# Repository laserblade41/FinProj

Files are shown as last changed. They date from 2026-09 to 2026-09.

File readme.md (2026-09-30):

<p align="center">
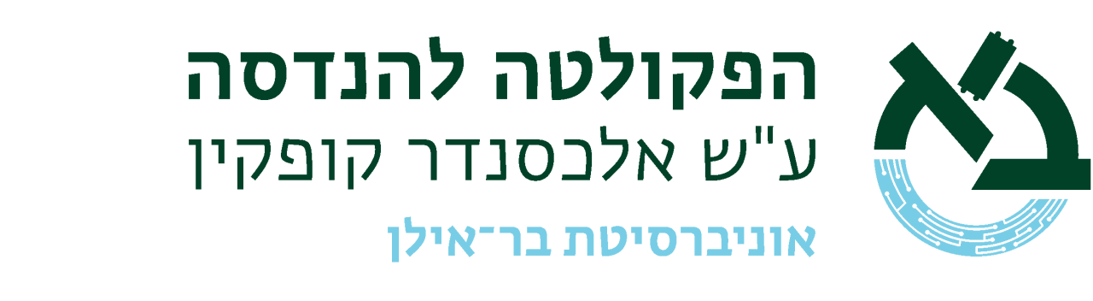
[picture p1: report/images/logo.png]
FinWatch logo
  
</p>

<h1 align="center">FinWatch</h1>

<p align="center">
  An open-source, Zephyr-powered BLE smartwatch with a modular I²C expansion port.<br>
  Final project in Computer Engineering, Bar-Ilan University (Project 323).
</p>

<p align="center">
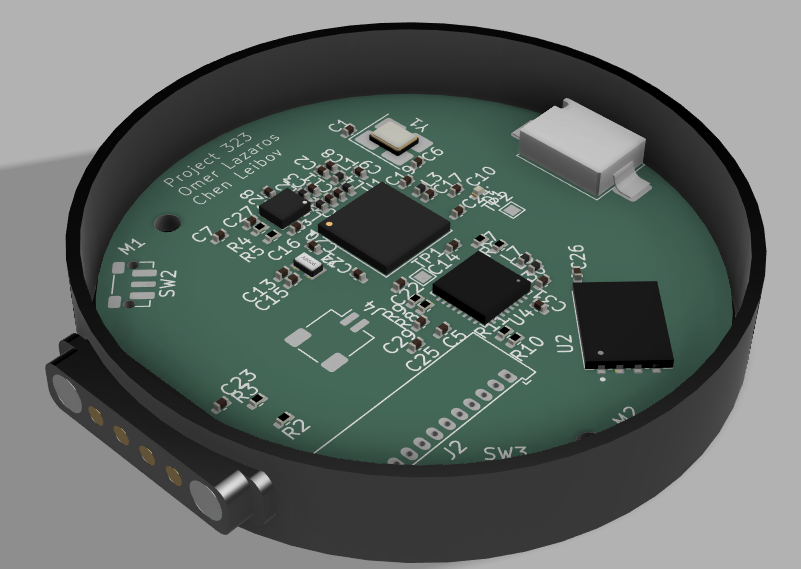
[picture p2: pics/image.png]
3D render of the FinWatch PCB in its case
  
</p>

## About

FinWatch is a complete custom smartwatch: the PCB (KiCad), the firmware (Zephyr RTOS / nRF Connect SDK) and a documented protocol for attaching new hardware to it.

Most smartwatches, commercial and open-source, are sealed. The sensors are fixed at manufacture, so a new measurement means a new watch. FinWatch asks whether a finished watch can be extended instead. A four-pin pogo connector on the back of the case carries 3.3 V, GND and an I²C bus. A module clipped onto it describes itself to the watch at runtime, and the firmware does not need to know about that module in advance.

The protocol that makes this work is the **FinWatch Module Protocol (FWMP)**. It is a self-describing, CRC-protected descriptor format. The host treats every byte from a module as untrusted and validates it before use.

The full write-up (design, protocol specification, verification, lessons learned) is in [report/main.pdf](report/main.pdf).

## Features

### Hardware

- **Nordic nRF5340** dual-core SoC (Cortex-M33 application core plus a separate network core running the BLE controller)
- **Nordic nPM1300** PMIC: Li-Po charging, fuel gauge, regulated 1.8 V and 3.3 V rails
- **GC9A01** 240×240 round LCD (SPI) with **CST816S** capacitive touch (I²C)
- **Bosch BMI270** 6-axis IMU with an any-motion interrupt, so the MCU sleeps until the wrist moves
- **Macronix MX25U51245G** 512 Mbit SPI NOR flash for assets and settings
- 32.768 kHz crystal for the RTC
- Two user buttons
- **4-pin pogo expansion port** (3.3 V, GND, SDA, SCL), level-shifted from the SoC's 1.8 V domain by a PCA9306
- 4-layer, 46 mm round PCB designed in KiCad (see [kicad/](kicad/))

### Software

- Zephyr RTOS on the nRF Connect SDK (NCS v3.2.1), with the application running in TF-M non-secure
- LVGL user interface: watch face showing time, date, battery and steps, plus a screen for the attached module
- Interrupt-driven step counting. The IMU wakes the host and the host only samples while the wrist is moving
- BLE with battery level notifications
- LittleFS on the external flash for persistent settings
- **FWMP host**: hot-plug detection, descriptor validation, input and output reports, adaptive polling, and I²C bus recovery
- Expansion runs at the lowest thread priority, so a misbehaving module cannot stall the display, sensors or radio link
- Hardware is described in the Devicetree only, so the same firmware runs on the nRF5340-DK and the custom PCB

## Expansion port and FWMP

FWMP is specified in three layers:

| Layer | What it defines |
| --- | --- |
| Electrical | Four contacts, 3.3 V supply, no pull-ups on the module side, level shifting on the watch |
| Logical | Register map and a TLV descriptor (identity, capabilities, report sizes, preferred poll rate) protected by a CRC-16 |
| Behavioural | Presence detection, enumeration, polling state machine, and recovery from faults |

The host rejects bad magic, bad protocol version, bad CRC, oversized lengths and TLV overruns. It also recovers a jammed bus. All of these paths were exercised with injected faults against a mock module. See section 4 of the report for the full specification and for how to write a compliant module.

## Hardware

<p align="center">
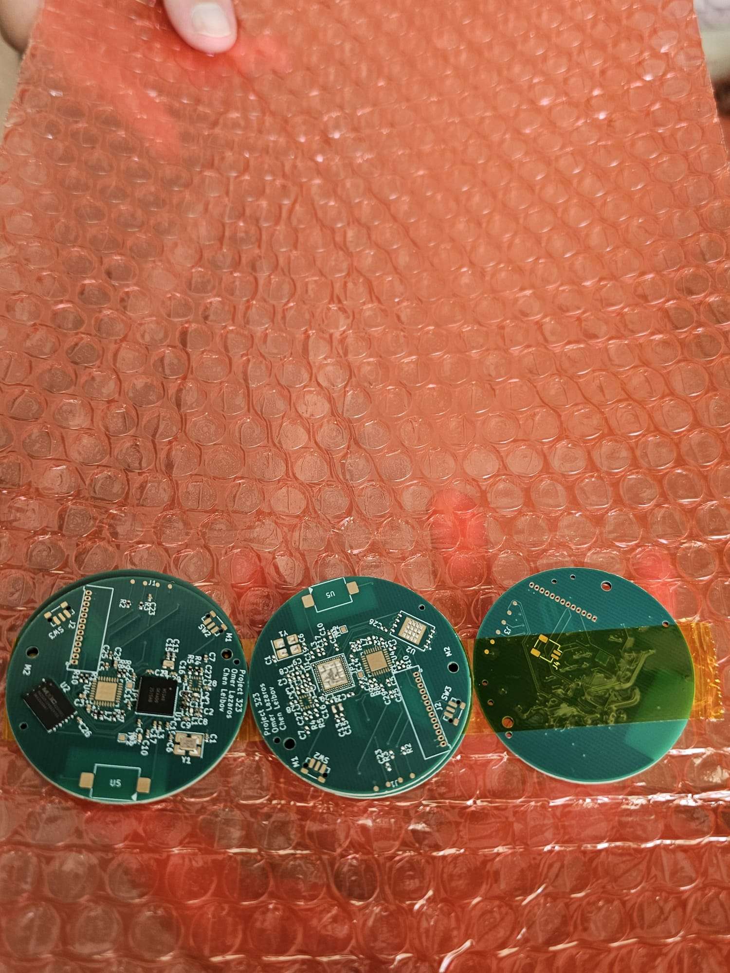
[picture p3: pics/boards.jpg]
Fabricated FinWatch PCBs
  
</p>

| Path | Contents |
| --- | --- |
| [kicad/](kicad/) | Schematic, PCB layout, custom symbols, footprints and 3D models |
| [kicad/watch_thing_alt.pdf](kicad/watch_thing_alt.pdf) | Schematic PDF |
| [kicad/components/board1_nrf5340/](kicad/components/board1_nrf5340/) | Gerber and drill files |

**Revision status**

- **Revision A** was manufactured and assembled. The power rails came up correctly, but `SWDIO` and `SWDCLK` were never routed, so the board could not be programmed.
- **Revision B** exposes SWD on test pads: `SWDIO` on TP4, `SWDCLK` on TP3, `nRESET` on TP2. The lesson from this defect became a pre-fabrication checklist, documented in the report.

## Firmware

<p align="center">
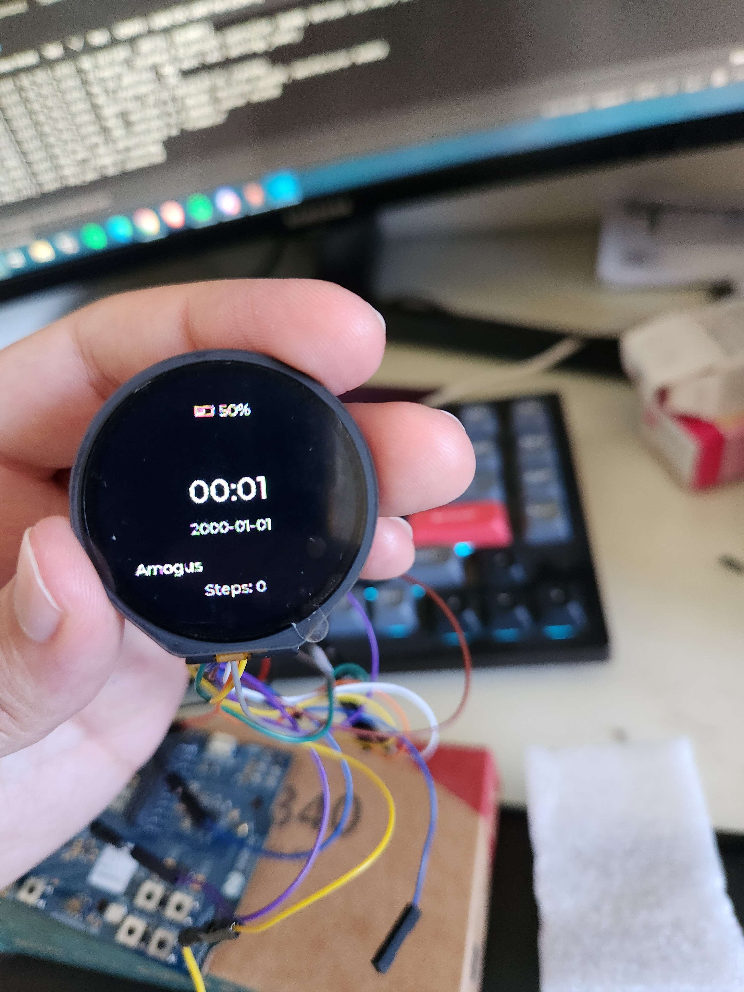
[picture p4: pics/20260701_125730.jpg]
FinWatch firmware running on the round display, wired to an nRF5340-DK
  
</p>

Above: the firmware running on the nRF5340-DK with the round display wired up.

```
code/
├── prj.conf                  Kconfig
├── boards/                   Devicetree overlays
├── child_image/hci_ipc.conf  Network-core BLE controller config
└── src/
    ├── main.c
    ├── ble/        BLE and battery notifications
    ├── buttons/    short and long press handling
    ├── display/    LVGL, watch face, module screen
    ├── expansion/  FWMP host, transport and mock module
    ├── pmic/       nPM1300: charger and fuel gauge
    ├── rtc/        timekeeping on the 32.768 kHz crystal
    ├── sensor/     BMI270 any-motion and step counting
    ├── storage/    external flash and LittleFS
    └── touch/      CST816S
```

### Building
```
IMPORTANT: the board itself does not include a bootloader to flash the firmware, in our case we used the one in the nRF5340DK.
```
1. Install the [nRF Connect SDK](https://docs.nordicsemi.com/bundle/ncs-latest/page/nrf/installation.html) **v3.2.1** and open an NCS shell.
2. Build and flash:

```sh
cd code
west build -b nrf5340dk/nrf5340/cpuapp/ns
west flash
```

To test the expansion protocol without any module hardware, enable the mock backend, which simulates a "Test Dial" module:

```sh
west build -b nrf5340dk/nrf5340/cpuapp/ns -- -DCONFIG_FINWATCH_EXPANSION_MOCK=y
```

> For the custom PCB, rename [code/boards/your_board.overlay](code/boards/your_board.overlay) to match your board target and confirm every pin marked `/* [PCB] */` against the schematic before flashing.

## Verification

- Firmware verified on the nRF5340-DK: display, touch, IMU, buttons and BLE
- FWMP verified against a mock module, including hot-plug and six injected-fault classes
- Revision A power rails verified; Revision B bring-up: *TODO*

Full results and their limits are in the report.

## Repository layout

| Folder | Contents |
| --- | --- |
| [code/](code/) | Zephyr firmware |
| [kicad/](kicad/) | PCB design files |
| [report/](report/) | Final project report (LaTeX and PDF) and presentation |
| [pics/](pics/) | Photos and renders |

## Authors

- **Omer Lazaros**
- **Chen Leibov**

Supervised by Prof. Leonid Yavitz. Project mentor: David Freud. Faculty of Engineering, Bar-Ilan University.

## Thanks

Thanks to the Zephyr Project, Nordic Semiconductor (nRF Connect SDK and its courses) and KiCad, whose open tools and documentation made this possible. [ZSWatch](https://github.com/ZSWatch/ZSWatch) was a major inspiration for this project.

## License

*TODO: pick a license (for example GPL-3.0 or MIT for the firmware and CERN-OHL for the hardware) and add a LICENSE file.*

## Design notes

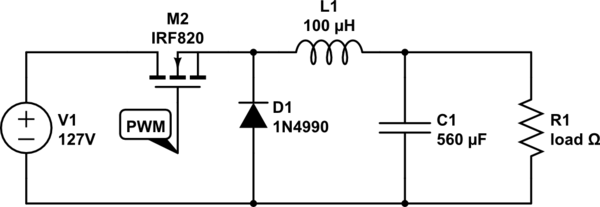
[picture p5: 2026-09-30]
report/images/buck.png

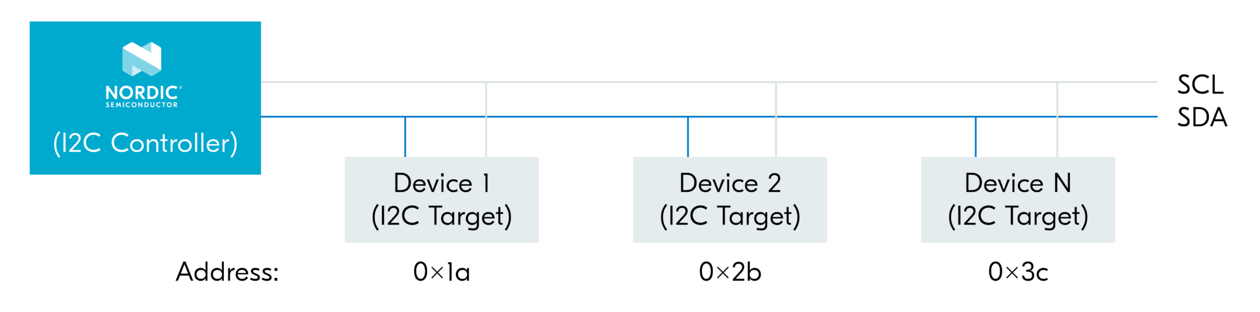
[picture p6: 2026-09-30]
report/images/i2c.png

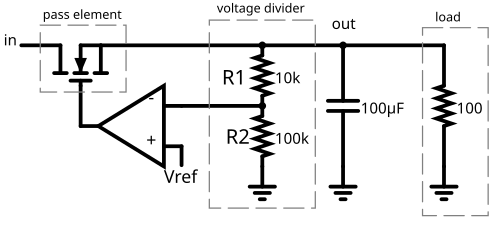
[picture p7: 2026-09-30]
report/images/ldo.png

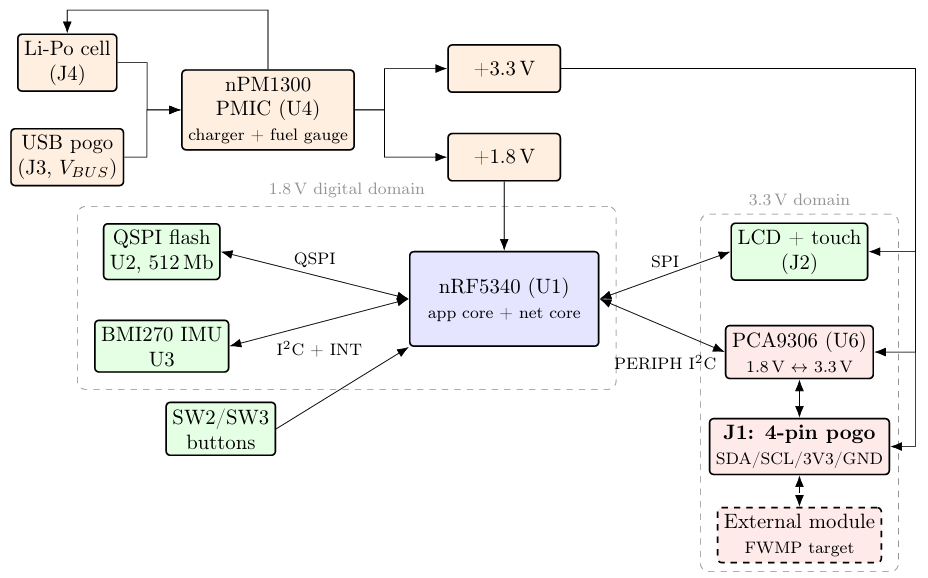
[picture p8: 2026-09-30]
report/presentation/pasted2.png

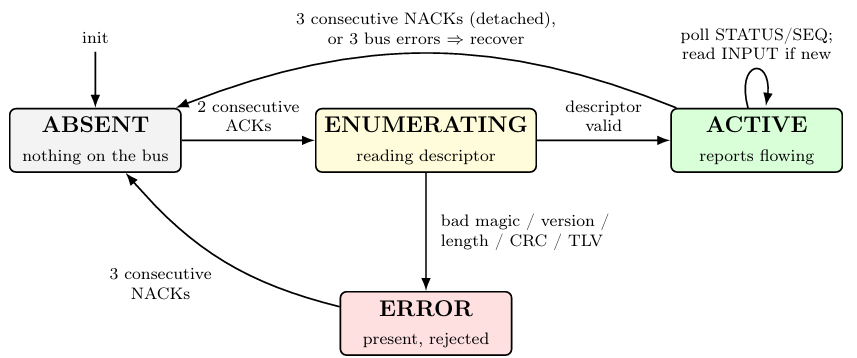
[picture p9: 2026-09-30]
report/presentation/pasted1.png

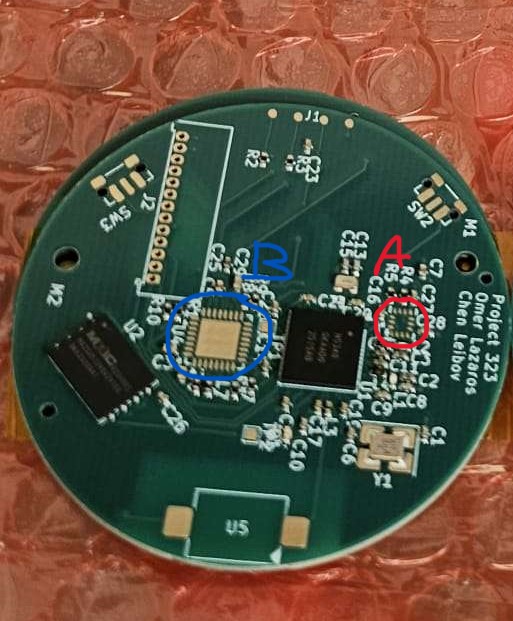
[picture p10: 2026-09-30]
pics/board_with_marks.jpg

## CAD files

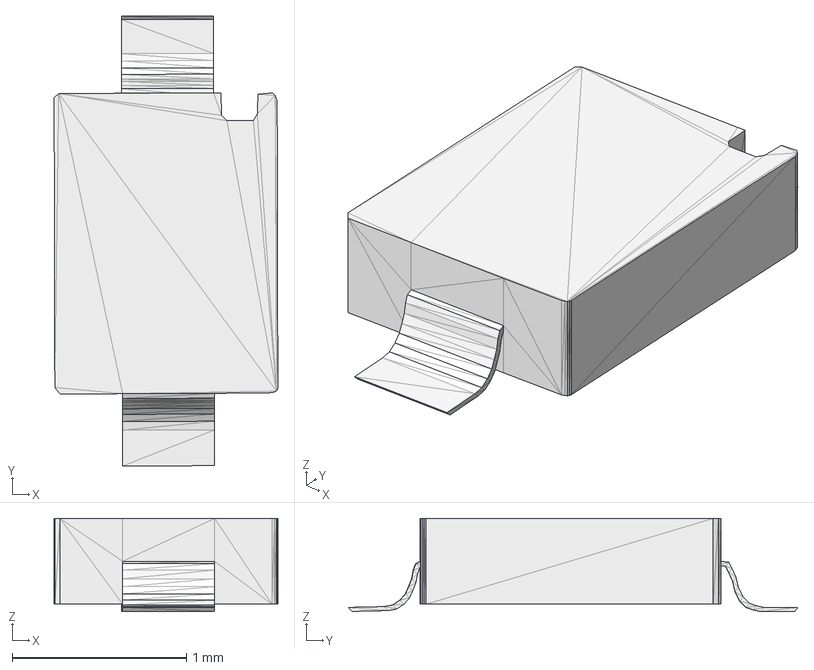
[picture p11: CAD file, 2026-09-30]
kicad/3d_models/antenna2.step
1.28 x 2.58 x 0.534 mm

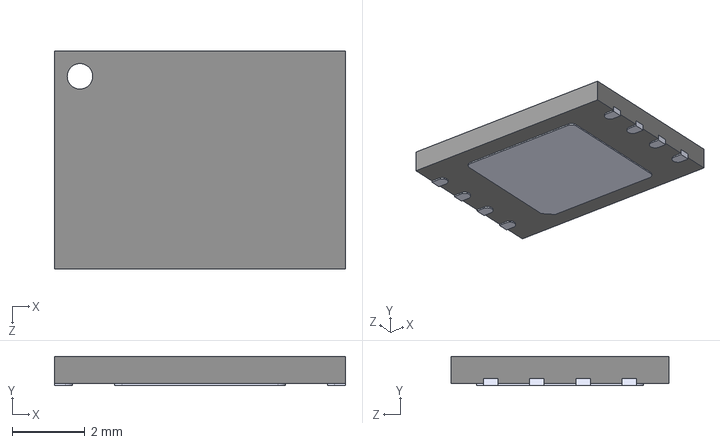
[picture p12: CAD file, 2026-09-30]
kicad/components/MX25L51245GZ2I-10G.step
8.00 x 0.8 x 6.00 mm

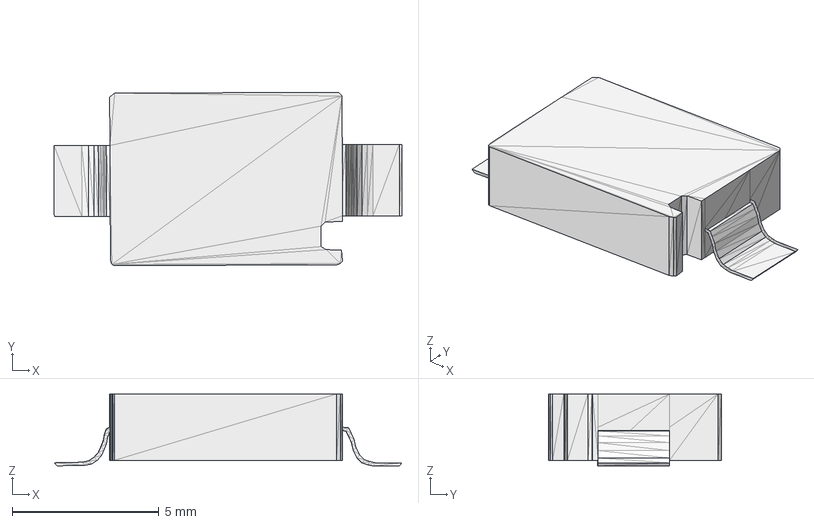
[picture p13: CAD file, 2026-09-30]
kicad/3d_models/antenna.step
11.9 x 5.91 x 2.46 mm

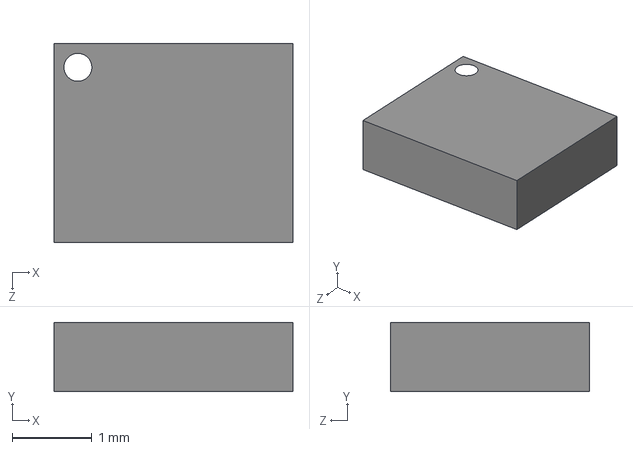
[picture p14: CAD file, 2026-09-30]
kicad/components/BMI270.step
3.00 x 0.87 x 2.50 mm

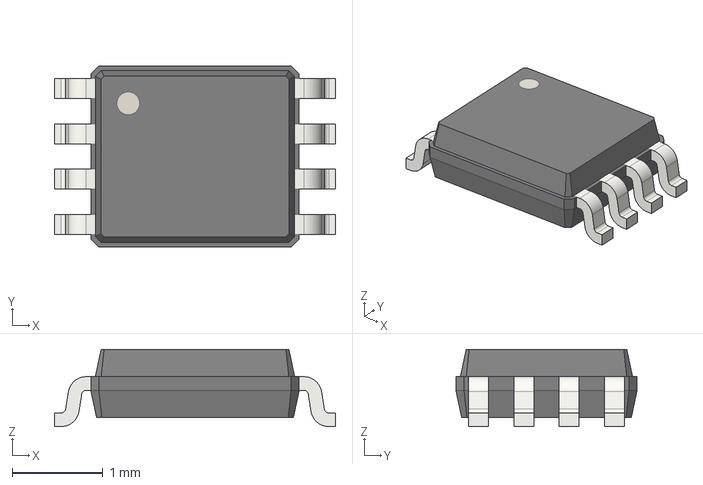
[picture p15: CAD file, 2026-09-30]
kicad/3d_models/pca9306.step
3.10 x 2.00 x 0.85 mm

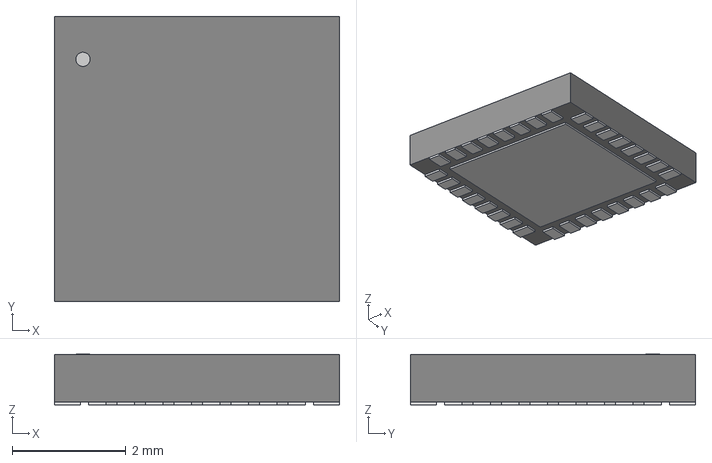
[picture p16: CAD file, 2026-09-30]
kicad/3d_models/QFN32_5X5_NOR.step
5.00 x 5.00 x 0.892 mm

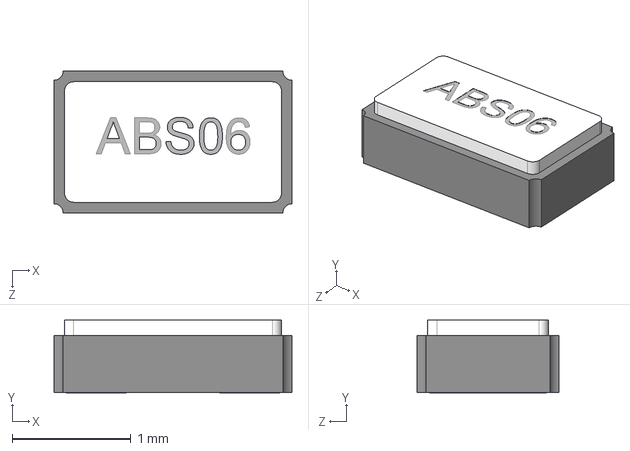
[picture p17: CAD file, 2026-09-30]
kicad/components/ABS06-32.768KHZ-T.step
2.01 x 0.612 x 1.19 mm

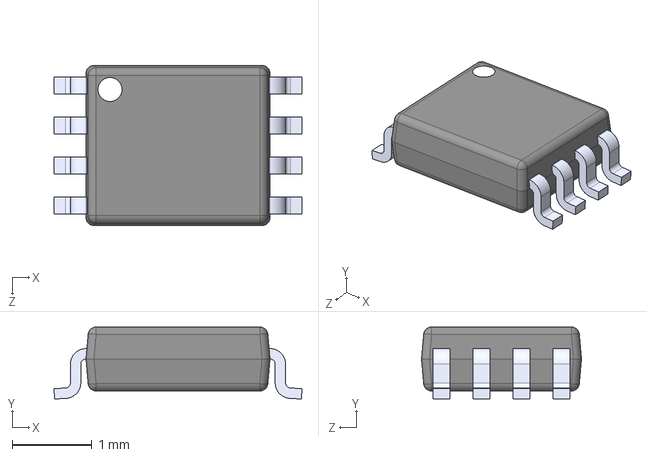
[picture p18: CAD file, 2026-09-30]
kicad/components/PCA9306TDCURQ1.step
3.10 x 0.9 x 2.00 mm

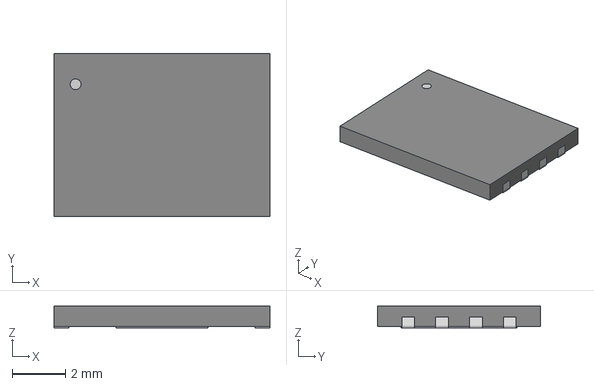
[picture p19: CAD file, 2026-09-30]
kicad/3d_models/WSON8_8X6XOP8_MAC.step
8.10 x 6.10 x 0.815 mm

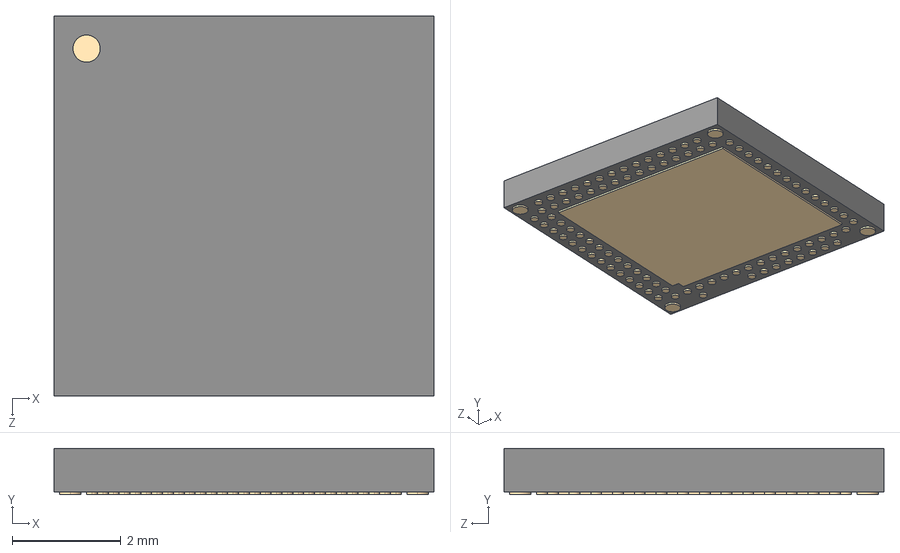
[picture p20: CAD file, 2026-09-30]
kicad/3d_models/NRF5340-QKAA-R7.STEP
7.00 x 0.85 x 7.00 mm

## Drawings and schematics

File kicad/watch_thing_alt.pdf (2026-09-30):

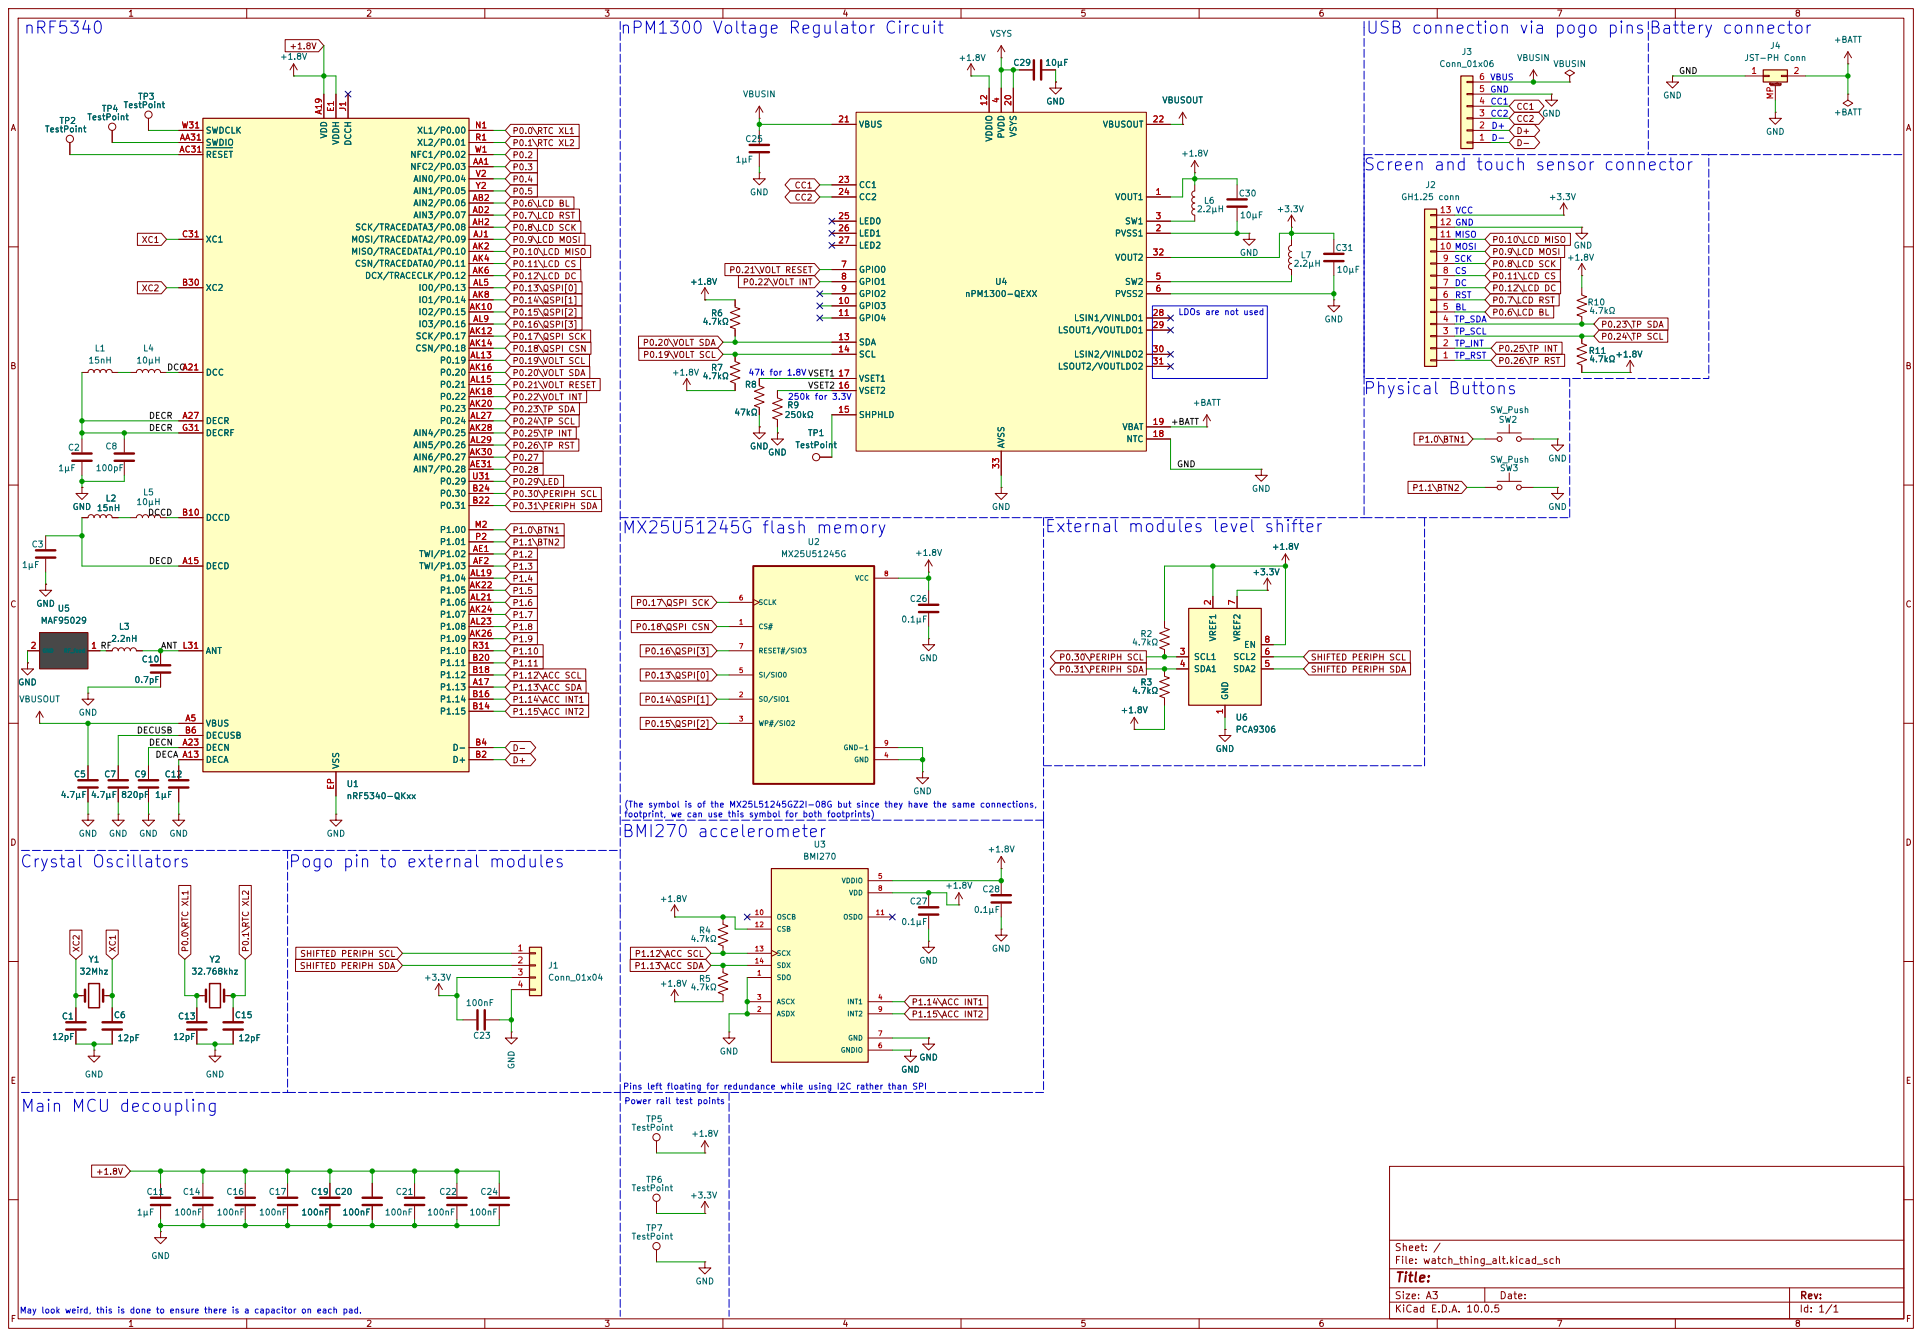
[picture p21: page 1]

P0.11\LCD CS P0.1\RTC XL2 P0.3 P0.2 P0.4 P0.0\RTC XL1 P0.7\LCD RST P0.6\LCD BL P0.5 P0.8\LCD SCK

JST-PH Conn GND
GND

TP_INT Screen and touch sensor connector

MOSI 250k for 3.3V BMI270 accelerometer
P0.9\LCD MOSI P0.11\LCD CS P0.19\VOLT SCL P0.20\VOLT SDA
SCK/P0.17 AK12 CSN/P0.18 AK14 P0.20 AK16 P0.22 AK18 P0.23 AK20 P1.05 AK22 P1.07 AK24 P1.09 AK26

SHIFTED PERIPH SCL SHIFTED PERIPH SDA XC2

P0.25\TP INT P0.26\TP RST P0.6\LCD BL P0.30\PERIPH SCL

LDOs are not used

P0.31\PERIPH SDA P0.22\VOLT INT P0.28 P1.1\BTN2

External modules level shifter

(The symbol is of the MX25L51245GZ2I-08G but since they have the same connections,
footprint, we can use this symbol for both footprints)

Pogo pin to external modules

Pins left floating for redundance while using I2C rather than SPI Main MCU decoupling

Size: A3 | Rev: | F Date:
KiCad E.D.A. 10.0.5 | Id: 1/1

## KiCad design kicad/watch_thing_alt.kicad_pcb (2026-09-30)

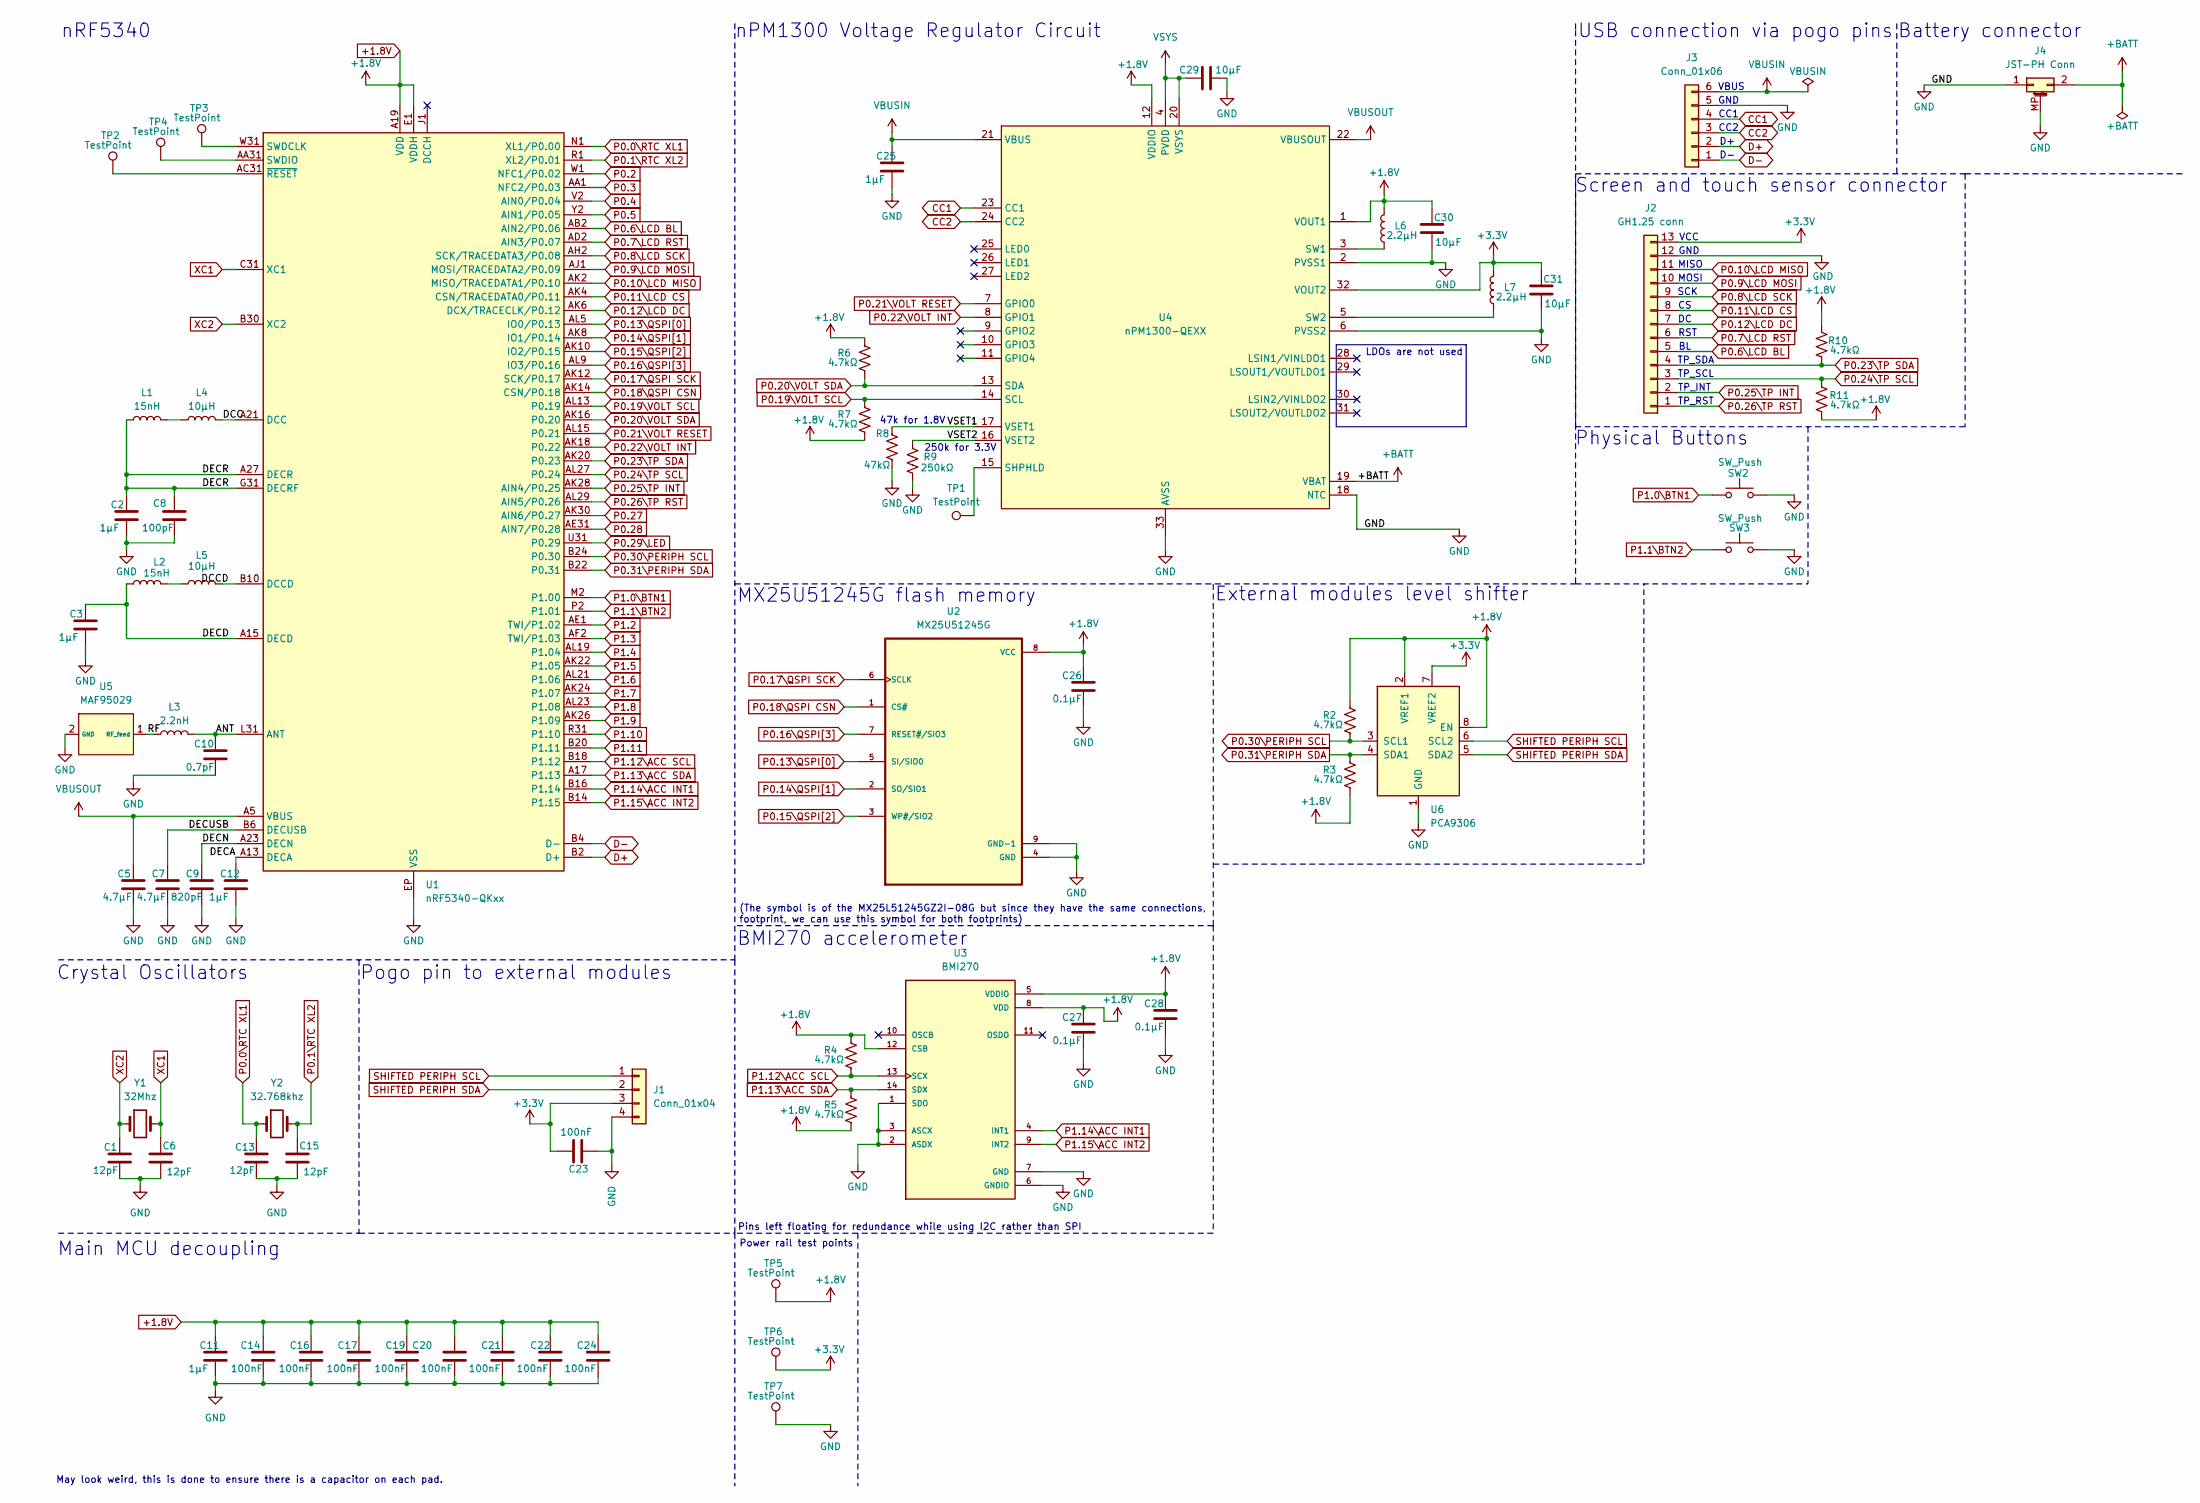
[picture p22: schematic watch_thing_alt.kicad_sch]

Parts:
C1, C6, C13, C15: 12pF; C_0402_1005Metric
C2, C3, C11, C12, C25: 1μF; C_0402_1005Metric
C5, C7: 4.7μF; C_0402_1005Metric
C8: 100pF; C_0402_1005Metric
C9: 820pF; C_0402_1005Metric
C10: 0.7pF; C_0402_1005Metric
C14, C16, C17, C19, C20, C21, C22, C23, C24: 100nF; C_0402_1005Metric
C26, C27, C28: 0.1μF; C_0402_1005Metric
C29, C30, C31: 10μF; C_0402_1005Metric
J1: Conn_01x04; 4_Pin_PogoPin
J2: GH1.25 conn; Molex_PicoBlade_53048-1310_1x13_P1.25mm_Horizontal
J3: Conn_01x06; 6_Pin_PogoPin
J4: JST-PH Conn; JST_SH_SM02B-SRSS-TB_1x02-1MP_P1.00mm_Horizontal
L1, L2: 15nH; L_0402_1005Metric
L3: 2.2nH; L_0402_1005Metric
L4, L5: 10μH; L_0402_1005Metric
L6, L7: 2.2μH; L_0402_1005Metric
R2, R3, R4, R5, R6, R7, R10, R11: 4.7kΩ; R_0402_1005Metric
R8: 47kΩ; R_0402_1005Metric
R9: 250kΩ; R_0402_1005Metric
SW2, SW3: SW_Push; SW_Push_1P1T-MP_NO_Horizontal_Alps_SKRTLAE010
TP1, TP2, TP3, TP4, TP5, TP6, TP7: TestPoint; TestPoint_Pad_1.0x1.0mm
U1: nRF5340-QKxx; Nordic_AQFN-94-1EP_7x7mm_P0.4mm
U2: MX25U51245G; SON127P600X800X80-9N
U3: BMI270; XDCR_BMI270
U4: nPM1300-QEXX; QFN-32-1EP_5x5mm_P0.5mm_EP3.6x3.6mm_ThermalVias
U5: MAF95029; MAF92029
U6: PCA9306; SOP50P310X90-8N
Y1: 32Mhz; Crystal_SMD_3225-4Pin_3.2x2.5mm_HandSoldering
Y2: 32.768khz; XTAL_ABS06-32.768KHZ-T

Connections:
+1.8V: C11.1, C14.1, C16.1, C17.1, C19.1, C20.1, C21.1, C22.1, C24.1, C26.1, C27.1, C28.1, C30.1, L6.2, R2.1, R3.2, R4.1, R5.2, R6.1, R7.2, R10.1, R11.2, TP5.1 (1_1), U1.A19 (VDD), U1.AC1 (VDD), U1.AG1 (VDD), U1.AJ31 (VDD), U1.AL3 (VDD), U1.AL7 (VDD), U1.AL11 (VDD), U1.AL17 (VDD), U1.AL25 (VDD), U1.B8 (VDD), U1.B28 (VDD), U1.C1 (VDD), U1.E1 (VDDH), U1.E31 (VDD), U1.L1 (VDD), U1.N31 (VDD), U1.U1 (VDD), U2.8 (VCC), U3.5 (VDDIO), U3.8 (VDD), U3.12 (CSB), U4.1 (VOUT1), U4.12 (VDDIO), U6.2 (VREF1), U6.8 (EN)
+3.3V: C23.2, C31.1, J1.3, J2.13, L7.2, TP6.1 (1_1), U4.32 (VOUT2), U6.7 (VREF2)
+BATT: J4.2, U4.19 (VBAT)
/ANT: C10.1, L3.2, U1.L31 (ANT)
/DCC: L4.2, U1.A21 (DCC)
/DCCD: L5.2, U1.B10 (DCCD)
/DECA: C12.1, U1.A13 (DECA)
/DECD: C3.1, L2.1, U1.A15 (DECD)
/DECN: C9.1, U1.A23 (DECN)
/DECR: C2.1, C8.1, L1.1, U1.A27 (DECR), U1.G31 (DECRF)
/DECUSB: C7.1, U1.B6 (DECUSB)
/RF: L3.1, U5.1 (RF_feed)
/VSET1: R8.2, U4.17 (VSET1)
/VSET2: R9.1, U4.16 (VSET2)
CC1: J3.4, U4.23 (CC1)
CC2: J3.3, U4.24 (CC2)
D+: J3.2, U1.B2 (D+)
D-: J3.1, U1.B4 (D-)
GND: C1.2, C2.2, C3.2, C5.2, C6.2, C7.2, C8.2, C9.2, C10.2, C11.2, C12.2, C13.2, C14.2, C15.2, C16.2, C17.2, C19.2, C20.2, C21.2, C22.2, C23.1, C24.2, C25.2, C26.2, C27.2, C28.2, C29.2, C30.2, C31.2, J1.4, J2.12, J3.5, J4.1, J4.MP (MountPin), R8.1, R9.2, SW2.2, SW3.2, TP7.1 (1_1), U1.EP (VSS), U2.4 (GND), U2.9 (GND-1), U3.1 (SDO), U3.2 (ASDX), U3.3 (ASCX), U3.6 (GNDIO), U3.7 (GND), U4.2 (PVSS1), U4.6 (PVSS2), U4.18 (NTC), U4.33 (AVSS), U5.2 (GND), U6.1 (GND)
unnamed: L1.2, L4.1
unnamed: L2.2, L5.1
unnamed: TP3.1 (1_1), U1.W31 (SWDCLK)
unnamed: TP4.1 (1_1), U1.AA31 (SWDIO)
unnamed: TP2.1 (1_1), U1.AC31 (~RESET)
unnamed: TP1.1 (1_1), U4.15 (SHPHLD)
unnamed: L6.1, U4.3 (SW1)
unnamed: L7.1, U4.5 (SW2)
P0.0\RTC XL1: C13.1, U1.N1 (XL1/P0.00), Y2.1
P0.1\RTC XL2: C15.1, U1.R1 (XL2/P0.01), Y2.2
P0.2: U1.W1 (NFC1/P0.02)
P0.3: U1.AA1 (NFC2/P0.03)
P0.4: U1.V2 (AIN0/P0.04)
P0.5: U1.Y2 (AIN1/P0.05)
P0.6\LCD BL: J2.5, U1.AB2 (AIN2/P0.06)
P0.7\LCD RST: J2.6, U1.AD2 (AIN3/P0.07)
P0.8\LCD SCK: J2.9, U1.AH2 (SCK/TRACEDATA3/P0.08)
P0.9\LCD MOSI: J2.10, U1.AJ1 (MOSI/TRACEDATA2/P0.09)
P0.10\LCD MISO: J2.11, U1.AK2 (MISO/TRACEDATA1/P0.10)
P0.11\LCD CS: J2.8, U1.AK4 (CSN/TRACEDATA0/P0.11)
P0.12\LCD DC: J2.7, U1.AK6 (DCX/TRACECLK/P0.12)
P0.13\QSPI[0]: U1.AL5 (IO0/P0.13), U2.5 (SI/SIO0)
P0.14\QSPI[1]: U1.AK8 (IO1/P0.14), U2.2 (SO/SIO1)
P0.15\QSPI[2]: U1.AK10 (IO2/P0.15), U2.3 (WP#/SIO2)
P0.16\QSPI[3]: U1.AL9 (IO3/P0.16), U2.7 (RESET#/SIO3)
P0.17\QSPI SCK: U1.AK12 (SCK/P0.17), U2.6 (SCLK)
P0.18\QSPI CSN: U1.AK14 (CSN/P0.18), U2.1 (CS#)
P0.19\VOLT SCL: R7.1, U1.AL13 (P0.19), U4.14 (SCL)
P0.20\VOLT SDA: R6.2, U1.AK16 (P0.20), U4.13 (SDA)
P0.21\VOLT RESET: U1.AL15 (P0.21), U4.7 (GPIO0)
P0.22\VOLT INT: U1.AK18 (P0.22), U4.8 (GPIO1)
P0.23\TP SDA: J2.4, R10.2, U1.AK20 (P0.23)
P0.24\TP SCL: J2.3, R11.1, U1.AL27 (P0.24)
P0.25\TP INT: J2.2, U1.AK28 (AIN4/P0.25)
P0.26\TP RST: J2.1, U1.AL29 (AIN5/P0.26)
P0.27: U1.AK30 (AIN6/P0.27)
P0.28: U1.AE31 (AIN7/P0.28)
P0.29\LED: U1.U31 (P0.29)
P0.30\PERIPH SCL: R2.2, U1.B24 (P0.30), U6.3 (SCL1)
P0.31\PERIPH SDA: R3.1, U1.B22 (P0.31), U6.4 (SDA1)
P1.0\BTN1: SW2.1, U1.M2 (P1.00)
P1.1\BTN2: SW3.1, U1.P2 (P1.01)
P1.2: U1.AE1 (TWI/P1.02)
P1.3: U1.AF2 (TWI/P1.03)
P1.4: U1.AL19 (P1.04)
P1.5: U1.AK22 (P1.05)
P1.6: U1.AL21 (P1.06)
P1.7: U1.AK24 (P1.07)
P1.8: U1.AL23 (P1.08)
P1.9: U1.AK26 (P1.09)
P1.10: U1.R31 (P1.10)
P1.11: U1.B20 (P1.11)
P1.12\ACC SCL: R4.2, U1.B18 (P1.12), U3.13 (SCX)
P1.13\ACC SDA: R5.1, U1.A17 (P1.13), U3.14 (SDX)
P1.14\ACC INT1: U1.B16 (P1.14), U3.4 (INT1)
P1.15\ACC INT2: U1.B14 (P1.15), U3.9 (INT2)
SHIFTED PERIPH SCL: J1.1, U6.6 (SCL2)
SHIFTED PERIPH SDA: J1.2, U6.5 (SDA2)
VBUSIN: C25.1, J3.6, U4.21 (VBUS)
VBUSOUT: C5.1, U1.A5 (VBUS), U4.22 (VBUSOUT)
VSYS: C29.1, U4.4 (PVDD), U4.20 (VSYS)
XC1: C6.1, U1.C31 (XC1), Y1.2
XC2: C1.1, U1.B30 (XC2), Y1.1

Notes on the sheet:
BMI270 accelerometer
Physical Buttons
TP_SCL
GND
LDOs are not used
Pogo pin to external modules
250k for 3.3V
47k for 1.8V
nPM1300 Voltage Regulator Circuit
MX25U51245G flash memory
VCC
Crystal Oscillators
CC2
External modules level shifter
MISO
USB connection via pogo pins
MOSI
May look weird, this is done to ensure there is a capacitor on each pad.
nRF5340
RST
TP_SDA
Pins left floating for redundance while using I2C rather than SPI
TP_RST
(The symbol is of the MX25L51245GZ2I-08G but since they have the same connections, footprint, we can use this symbol for both footprints)
Screen and touch sensor connector
TP_INT
VBUS
SCK
Main MCU decoupling
GND
Power rail test points
CC1
Battery connector

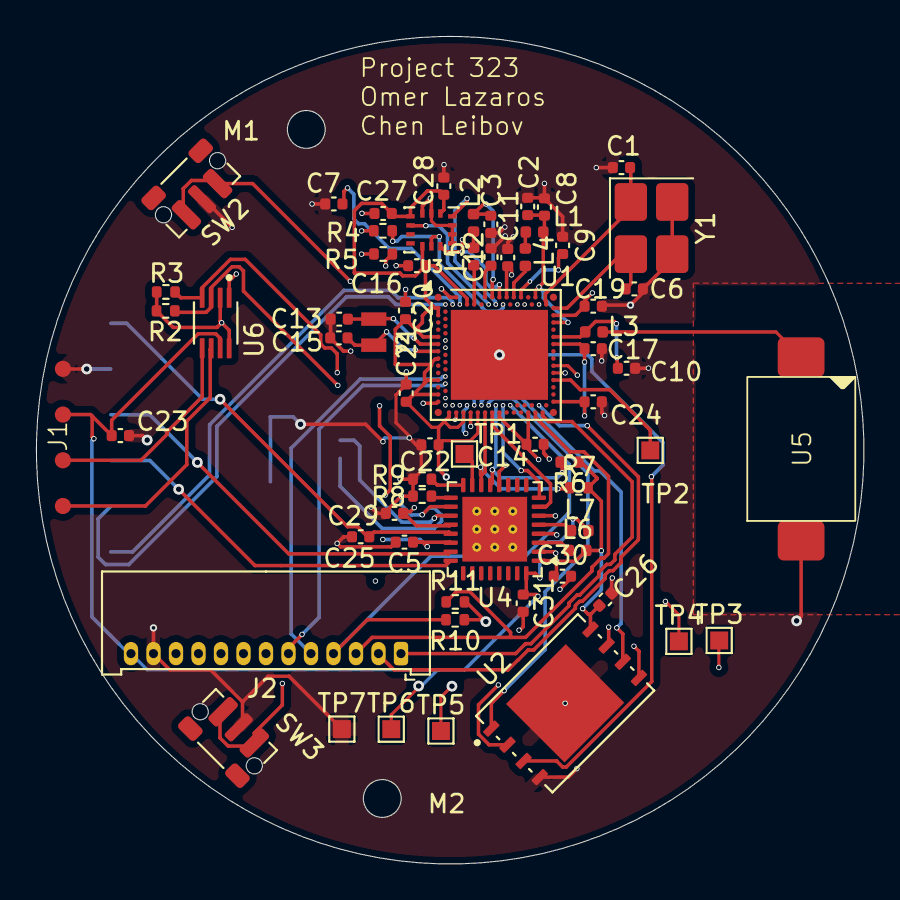
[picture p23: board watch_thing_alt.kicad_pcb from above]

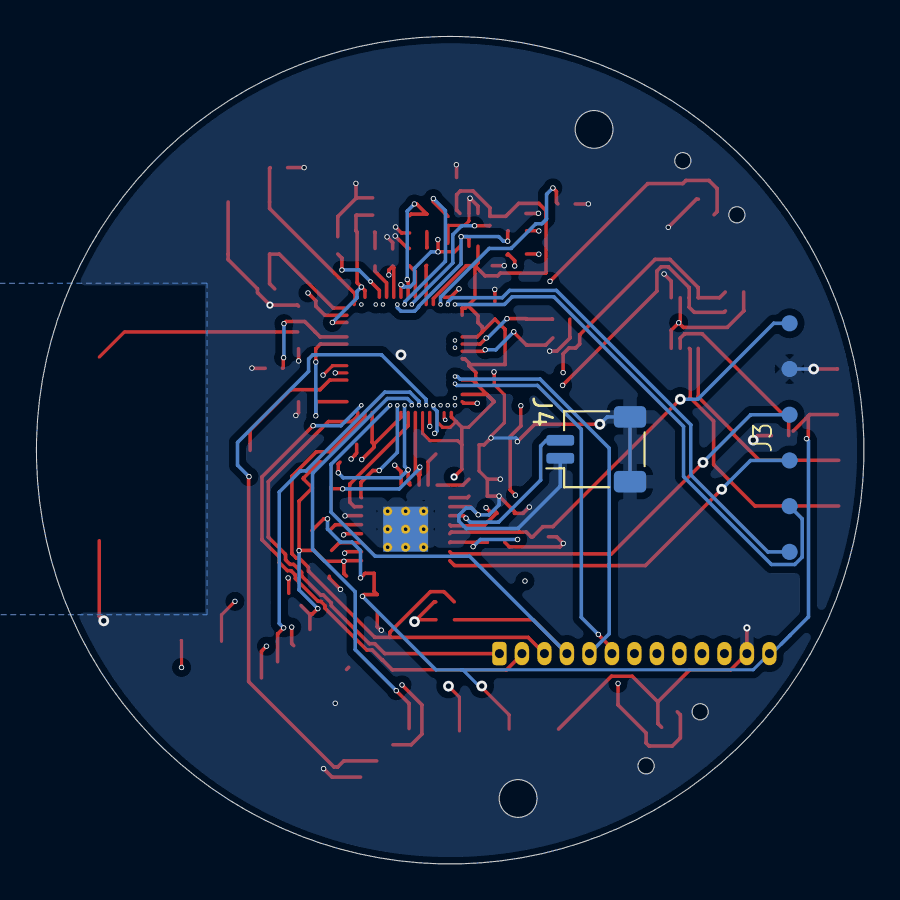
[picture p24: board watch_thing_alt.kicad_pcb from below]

Board: 4 copper layers, 46.0 x 46.0 mm, 69 parts (2 on the bottom side), 65 nets.

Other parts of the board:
M1, M2: MountingHole_2.1mm

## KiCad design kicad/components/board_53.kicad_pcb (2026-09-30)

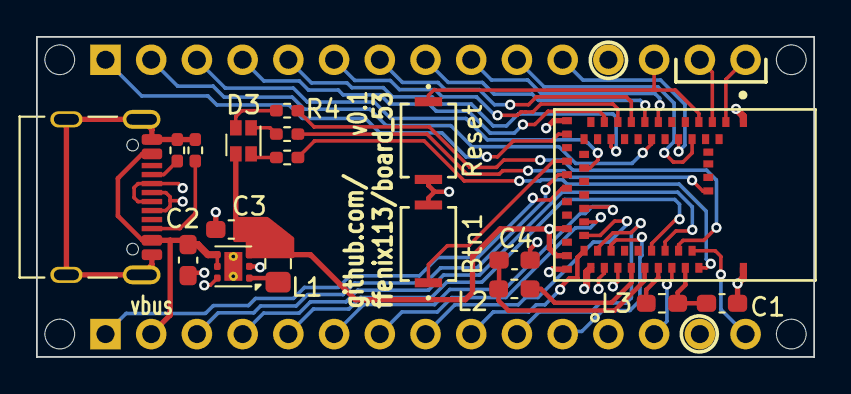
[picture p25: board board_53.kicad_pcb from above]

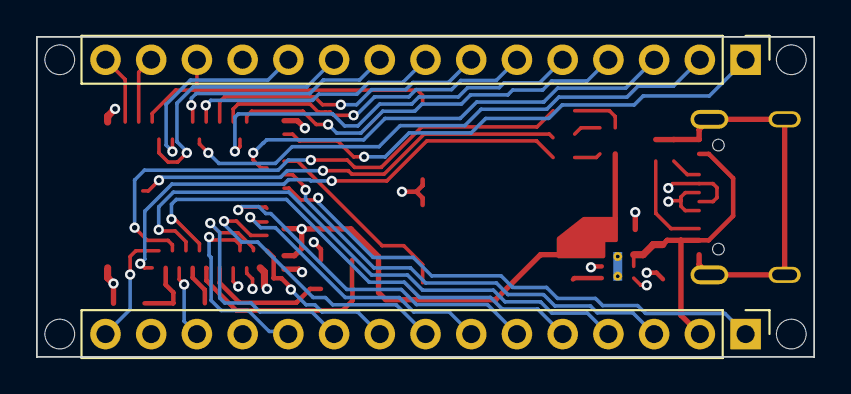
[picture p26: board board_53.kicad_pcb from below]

Board: 4 copper layers, 43.2 x 17.8 mm, 24 parts (2 on the bottom side), 45 nets.

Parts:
C1, C4: CL10A105KQ8NNNC; C_0603_1608Metric_Pad1.08x0.95mm_HandSolder
C2, C3: GRM188R60J106ME47D; C_0603_1608Metric_Pad1.08x0.95mm_HandSolder
D3: LTST-C19HE1WT; LED_LiteOn_LTST-C19HE1WT
J1: Analog; PinHeader_1x15_P2.54mm_Vertical
J2: Digital; PinHeader_1x15_P2.54mm_Vertical
J3: 12402012E212A; AMPHENOL_12402012E212A
L1: WIP201612S-2R2MLDG; L_0805_2012Metric_Pad1.15x1.40mm_HandSolder
L2, L3: MLZ1608N100LT000; L_0603_1608Metric_Pad1.05x0.95mm_HandSolder
MH1, MH2, MH3, MH4: MountingHole_65mil
R1, R4, R5: ERJ-2RKF3300X; R_0402_1005Metric_Pad0.72x0.64mm_HandSolder
R3, R7: ERJ-2GEJ512X; R_0402_1005Metric_Pad0.72x0.64mm_HandSolder
SW1, SW2: CS1213AGF160; SW_CS1213AGF260_CRS
U1: MDBT53-1M; Raytac-MDBT53-1M-MFG
U2: TPS62291DRVR; WSON-6-1EP_2x2mm_P0.65mm_EP1x1.6mm_ThermalVias

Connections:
+3V3: C3.1, D3.4, J1.12, L1.2, U1.38 (VDD), U1.41 (VDDH), U2.3 (FB)
/*D5: J1.9, U1.43 (P1.01)
/*P0.08/SS: J2.3, U1.29 (P0.08)
/A0: J1.7, U1.37 (P0.04)
/A1: J1.8, U1.39 (P0.05)
/A3: J2.4, U1.20 (P0.07)
/A4/SDA: J2.11, U1.9 (P0.25)
/A5/SCL: J2.10, U1.7 (P0.26)
/A7: J1.11, U1.47 (P1.15)
/BL_LED: R5.2, U1.60 (P0.28)
/D0/RX: J2.1, U1.25 (P0.22)
/D1/TX: J2.2, U1.13 (P0.20)
/D4: J1.10, U1.45 (P1.00)
/D14: J1.13, U1.56 (P0.31)
/GR_LED: R1.2, U1.65 (P0.29)
/P0.02/NFC1: J1.1, U1.32 (P0.02/NFC1)
/P0.03/NFC2: J1.3, U1.30 (P0.03/NFC2)
/P0.06/A2: J1.6, U1.35 (P0.06)
/P0.09/MOSI: J2.5, U1.19 (P0.09)
/P0.10/MISO: J2.6, U1.18 (P0.10)
/P0.16: SW2.1, U1.28 (P0.16)
/P0.18: J2.7, U1.16 (P0.18)
/P0.19: J2.8, U1.14 (P0.19)
/P0.21: J2.9, U1.12 (P0.21)
/P1.10: J1.15, U1.59 (P1.10)
/P1.11: J1.4, U1.55 (P1.11)
/P1.12: J1.5, U1.53 (P1.12)
/RD_LED: R4.2, U1.57 (P0.30)
/SWDCLK: J2.15, U1.2 (SWCLK)
/SWDIO: J2.14, U1.4 (SWDIO)
/~RESET: J2.13, SW1.1, U1.6 (~RESET)
GND: C1.2, C2.2, C3.2, C4.1, J1.14, J2.12, J3.A1_B12 (GND), J3.B1_A12 (GND__1), J3.SH1 (SHIELD), J3.SH2 (SHIELD__1), J3.SH3 (SHIELD__2), J3.SH4 (SHIELD__3), R3.1, R7.2, SW1.2, SW2.2, U1.1 (GND), U1.24 (GND), U1.42 (GND), U1.61 (GND), U2.2 (MODE), U2.6 (GND)
unnamed: D3.1, R4.1
unnamed: D3.2, R1.1
unnamed: D3.3, R5.1
unnamed: J3.A5 (CC1_A), R7.1
unnamed: J3.B5 (CC1_B), R3.2
unnamed: L3.2, U1.54 (DCC)
unnamed: L2.2, U1.50 (DCCD)
unnamed: C4.2, L2.1, U1.52 (DECD)
unnamed: C1.1, L3.1, U1.58 (DECR)
unnamed: L1.1, U2.1 (SW)
USB_DN: J3.A7 (D-_A), J3.B7 (D-_B), U1.48 (D-)
USB_DP: J3.A6 (D+_A), J3.B6 (D+_B), U1.46 (D+)
VBUS: C2.1, J1.2, J3.A4_B9 (VBUS), J3.B4_A9 (VBUS__1), U1.44 (VBUS), U2.4 (EN), U2.5 (VIN)

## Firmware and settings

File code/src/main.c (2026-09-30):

#include <zephyr/kernel.h>
#include <zephyr/logging/log.h>

#include "rtc/rtc.h"
#include "pmic/pmic.h"
#include "sensor/sensor.h"
#include "touch/touch.h"
#include "display/display.h"
#include "display/watchface.h"
#include "storage/storage.h"
#include "ble/ble.h"
#include "buttons/buttons.h"
#include "expansion/expansion.h"

LOG_MODULE_REGISTER(main, LOG_LEVEL_INF);

/* ---- Button handler ---- */

static void on_button(uint8_t btn_idx, btn_event_t event)
{
    if (btn_idx == 0 && event == BTN_SHORT_PRESS) {
        /* BTN0 short: cycle screens (only watch face for now) */
        LOG_DBG("BTN0 short");
    } else if (btn_idx == 0 && event == BTN_LONG_PRESS) {
        /* BTN0 long: reset step counter */
        sensor_reset_step_count();
        LOG_INF("Step counter reset");
    } else if (btn_idx == 1 && event == BTN_SHORT_PRESS) {
        /* BTN1 short: toggle backlight */
        LOG_DBG("BTN1 short");
    } else if (btn_idx == 1 && event == BTN_LONG_PRESS) {
        /* BTN1 long: (reserved for power menu) */
        LOG_INF("BTN1 long press");
    }
}

/* ---- Expansion module events ---- */

/* Runs on the expansion poll thread, logging only, no LVGL calls.
 * The module screen refreshes itself from its own LVGL timer. */
static void on_expansion_event(enum expansion_state state,
                               const struct expansion_info *info)
{
    switch (state) {
    case EXP_ACTIVE:
        LOG_INF("Module attached: \"%s\" (%04X:%04X)",
                info->name, info->vid, info->pid);
        break;
    case EXP_ABSENT:
        LOG_INF("Module detached");
        break;
    case EXP_ERROR:
        LOG_WRN("Module present but descriptor rejected");
        break;
    case EXP_ENUMERATING:
        LOG_DBG("Module enumerating");
        break;
    }
}

/* ---- Background update thread- 1 Hz watch-face refresh ---- */

#define UPDATE_STACK   1024
#define UPDATE_PRIO    9
#define UPDATE_PERIOD  1000   /* ms */

static void update_thread_fn(void *p1, void *p2, void *p3)
{
    ARG_UNUSED(p1); ARG_UNUSED(p2); ARG_UNUSED(p3);

    struct watch_settings settings = {
        .tz_offset_hours = 0,
        .step_goal       = 10000,
        .brightness      = 80,
    };
    storage_load_settings(&settings);

    uint8_t last_pct = 0;
    int batt_tick = 0;

    while (1) {
        /* ---- Time ---- */
        struct rtc_time t;
        rtc_get_time(&t);
        watchface_update_time(&t);

        /* ---- Battery: poll every 10 s ---- */
        if (++batt_tick >= 10) {
            batt_tick = 0;
            uint8_t pct = pmic_get_batt_percent();
            bool    chg = pmic_is_charging();
            watchface_update_battery(pct, chg);
            if (pct != last_pct) {
                ble_notify_battery(pct);
                last_pct = pct;
            }
        }

        /* ---- Steps ---- */
        watchface_update_steps(sensor_get_step_count());

        k_msleep(UPDATE_PERIOD);
    }
}

K_THREAD_DEFINE(update_tid, UPDATE_STACK,
                update_thread_fn, NULL, NULL, NULL,
                UPDATE_PRIO, 0, 0);

/* ---- Main ---- */

int main(void)
{
    int ret;

    LOG_INF("FinWatch booting...");

    ret = rtc_module_init();
    if (ret < 0) {
        LOG_WRN("RTC init: %d (time resets on power cycle)", ret);
    }

    ret = pmic_module_init();
    if (ret < 0) {
        LOG_WRN("PMIC init: %d", ret);
    }

    /* Pass display_wake as the motion callback, wrist-raise wakes screen */
    ret = sensor_module_init(display_wake);
    if (ret < 0) {
        LOG_WRN("Sensor init: %d", ret);
    }

    /*
     * DK bring-up: external SPI-NOR flash isn't populated on the DK.
     * fs_mount() hard-faults (SecureFault) rather than failing gracefully,
     * because DT_FIXED_PARTITION_ID(ext_storage_partition) collides with
     * the DK's internal storage_partition ID, a separate bug to revisit
     * once real flash hardware is wired up. Skip storage until then.
     */
#if 0
    ret = storage_module_init();
    if (ret < 0) {
        LOG_WRN("Storage init: %d", ret);
    }
#endif

    ret = buttons_module_init(on_button);
    if (ret < 0) {
        LOG_WRN("Buttons init: %d", ret);
    }

    /* Touch must be ready before display so LVGL indev is registered */
    ret = touch_module_init();
    if (ret < 0) {
        LOG_WRN("Touch init: %d", ret);
    }

    ret = display_module_init();
    if (ret < 0) {
        LOG_ERR("Display init: %d: halting", ret);
        return ret;
    }

    ret = ble_module_init();
    if (ret < 0) {
        LOG_WRN("BLE init: %d", ret);
    }

    /* Expansion port is optional hardware, never let it block boot. */
    ret = expansion_module_init(on_expansion_event);
    if (ret < 0) {
        LOG_WRN("Expansion init: %d", ret);
    }

    LOG_INF("FinWatch running");
    return 0;
}

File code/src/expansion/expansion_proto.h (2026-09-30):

/*
 * FinWatch Module Protocol (FWMP) v1 — wire format.
 *
 * Transport: I2C. The watch is the controller (host); an expansion module
 * attached to the pogo pins is the target, at a fixed address.
 *
 * The module exposes a flat register space read with the standard
 * "write offset, repeated START, read N" EEPROM idiom (i2c_write_read()).
 * Low registers hold a self-describing descriptor; high registers carry
 * runtime input/output reports.
 *
 * This header is wire format ONLY — no Zephyr dependencies, so the same
 * file can be shared verbatim with module-side firmware later.
 */

#pragma once

#include <stdint.h>

/* ---- Transport ---- */

/* 7-bit target address. Must stay outside the I2C reserved ranges
 * (0x00-0x07 and 0x78-0x7F). Dedicated bus, one module at a time. */
#define FWMP_I2C_ADDR        0x42

#define FWMP_MAGIC0          0x46  /* 'F' */
#define FWMP_MAGIC1          0x57  /* 'W' */
#define FWMP_PROTO_VER       0x01

/* ---- Descriptor register map ---- */

#define FWMP_REG_MAGIC0      0x00
#define FWMP_REG_MAGIC1      0x01
#define FWMP_REG_PROTO_VER   0x02
#define FWMP_REG_DESC_LEN    0x03  /* total descriptor bytes, incl. header + TLVs + CRC */
#define FWMP_REG_VID_L       0x04
#define FWMP_REG_VID_H       0x05
#define FWMP_REG_PID_L       0x06
#define FWMP_REG_PID_H       0x07
#define FWMP_REG_CAPS        0x08
#define FWMP_REG_N_TLV       0x09
#define FWMP_REG_TLV_START   0x0A

/* Fixed-size part of the descriptor, before the TLV entries. */
#define FWMP_DESC_HDR_LEN    FWMP_REG_TLV_START  /* 10 bytes */

/* CRC16 occupies the final two bytes of the descriptor. */
#define FWMP_DESC_CRC_LEN    2

/* Hard upper bound on a descriptor. The host rejects anything larger rather
 * than trusting a length byte from an untrusted module. */
#define FWMP_DESC_MAX_LEN    128

/* ---- Capability flags (FWMP_REG_CAPS) ---- */

#define FWMP_CAP_INPUT       (1U << 0)  /* module produces input reports */
#define FWMP_CAP_OUTPUT      (1U << 1)  /* module accepts output reports */

/* ---- TLV entry types ---- */

#define FWMP_TLV_NAME          0x01  /* ASCII, not NUL-terminated on the wire */
#define FWMP_TLV_INPUT_REPORT  0x02  /* [report_len:1][poll_hint_ms:2 LE] */
#define FWMP_TLV_OUTPUT_REPORT 0x03  /* [report_len:1] */
#define FWMP_TLV_ICON_ID       0x04  /* [icon_id:1] */

#define FWMP_NAME_MAX_LEN      24

/* ---- Runtime register map ---- */

#define FWMP_REG_STATUS        0x80
#define FWMP_REG_SEQ           0x81  /* bumped on each new input report */
#define FWMP_REG_INPUT         0x82
#define FWMP_REG_OUTPUT        0xC0

#define FWMP_REPORT_MAX_LEN    32

/* ---- STATUS bits (FWMP_REG_STATUS) ---- */

#define FWMP_STATUS_DATA_READY (1U << 0)
#define FWMP_STATUS_ERROR      (1U << 1)
#define FWMP_STATUS_BUSY       (1U << 2)

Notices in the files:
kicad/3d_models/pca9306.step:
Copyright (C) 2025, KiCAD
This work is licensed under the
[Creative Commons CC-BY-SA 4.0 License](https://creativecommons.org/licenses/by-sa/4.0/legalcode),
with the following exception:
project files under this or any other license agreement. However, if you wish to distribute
